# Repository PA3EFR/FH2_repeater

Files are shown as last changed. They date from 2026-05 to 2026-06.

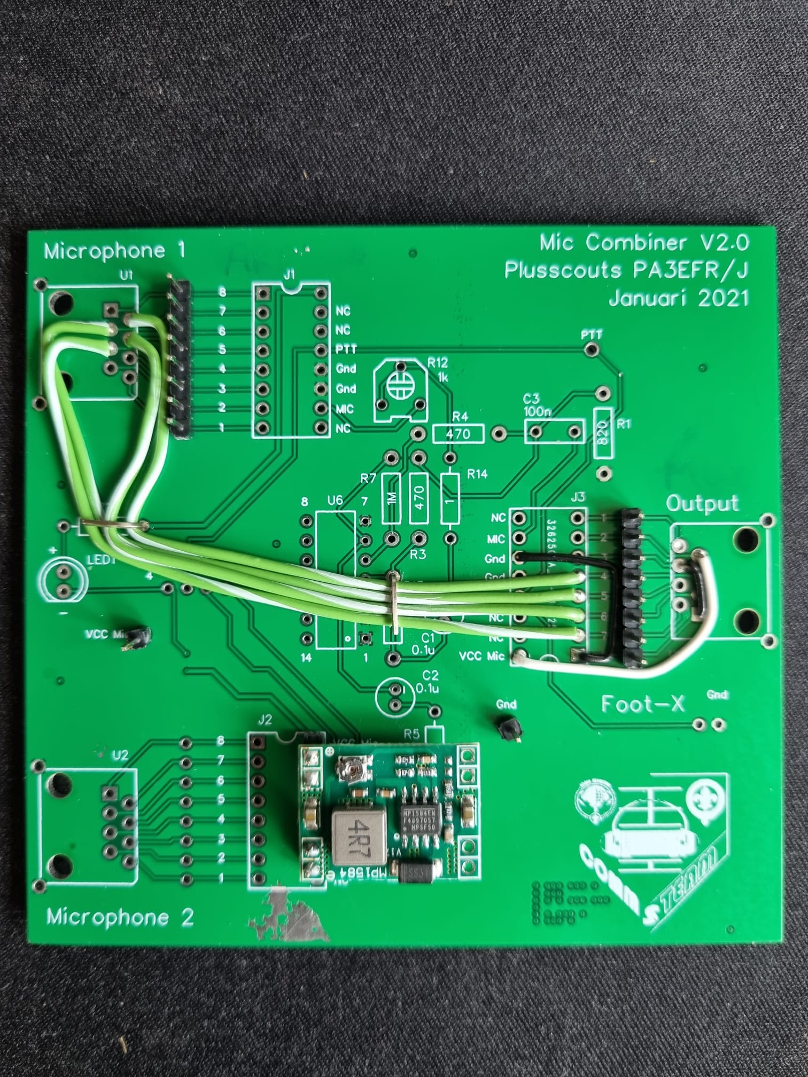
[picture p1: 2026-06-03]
Arduino Nano - 991/WhatsApp Image 2026-06-02 at 10.33.48.jpeg

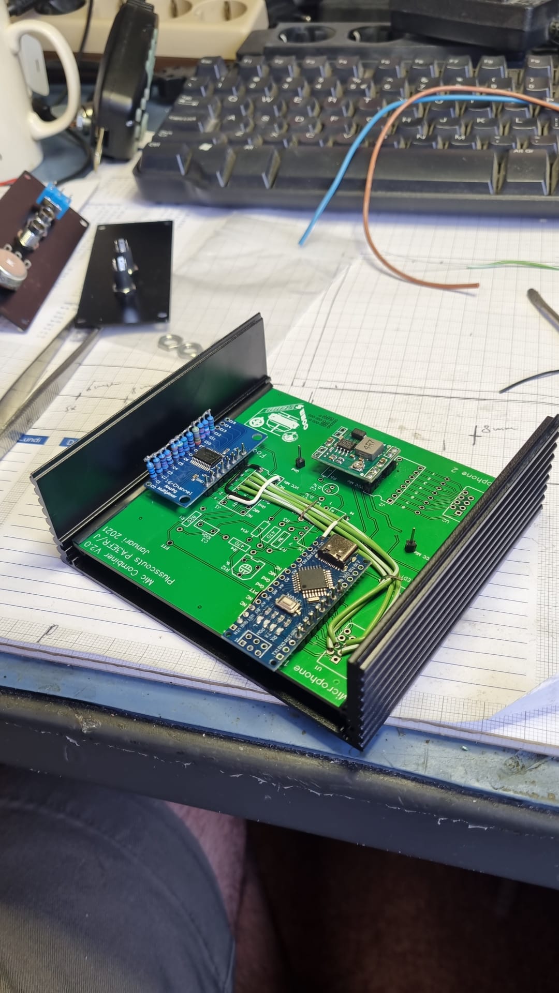
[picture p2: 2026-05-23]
Arduino Nano - 991/WhatsApp Image 2026-05-23 at 11.17.42.jpeg

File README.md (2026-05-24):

**FH-2 Repeater - Functional and Technical Descriptions**

**Functional Description**
The FH-2 Repeater is an Arduino NANO-based system that provides automated control for the Yaesu FH-2 Voice keyer, enabling users to send pre-programmed (CQ) messages at configurable intervals. This controller bridges the gap between traditional manual keying and modern automation, making it particularly useful for contest stations and field operations where consistent, timed CQ transmissions are essential.

The system operates by reading the FH-2's button matrix through an analog voltage sensing mechanism, where each button produces a distinct voltage level through a resistor network. When a button is pressed, the controller activates the corresponding channel on a 16-channel analog multiplexer (74HC4067) to send the appropriate control pulse to the FH-2 unit. The core functionality centers on the interval repeat feature, which allows buttons 1 through 5 to automatically repeat their transmission at user-defined intervals ranging from 10 to 60 seconds. A front-panel potentiometer provides real-time adjustment of the interval timing, while a toggle switch enables or disables the repeat functionality entirely.

The user interface consists of minimal but effective visual indicators: a pulse LED flashes briefly when a transmission occurs, and a status LED illuminates when an interval cycle is actively running. All system information, including button changes, interval modifications, and cycle status, is streamed to the serial monitor at 9600 baud, allowing operators to verify correct operation and troubleshoot any issues. The interval cycle initiates when button 1, 2, 3, 4, or 5 is pressed and continues automatically until the same button is pressed again or the repeat function is disabled via the toggle switch. Pressing any other button immediately terminates an active interval cycle, providing a quick emergency stop mechanism.

The controller's design philosophy prioritizes reliability and simplicity, using only through-hole components for easy construction and maintenance. The debounce algorithm ensures that only genuine button presses are registered, preventing false triggers from mechanical switch bounce. The multiplexer timeout feature ensures that no channel remains selected indefinitely, protecting both the multiplexer and the connected equipment from potential damage due to software or hardware faults.

**Technical Description**
The FH-2 Repeater employs an Arduino NANO (ATmega328P) as its processing core, utilizing the microcontroller's analog-to-digital converter for button matrix scanning and its digital I/O pins for multiplexer control and LED indication. The pin configuration has been carefully chosen to optimize the limited I/O available on the NANO form factor while maintaining logical organization of the various subsystems.

Pin Assignment Summary:

Function	Pin	Description
ADC Input	A0 (Pin 14)	FH-2 button voltage measurement
Interval Control	A1 (Pin 15)	Potentiometer wiper for interval adjustment
MUX S0-S3	D2-D5 (Pins 2-5)	4-bit multiplexer channel selection
MUX Enable	D6 (Pin 6)	Active-low enable for 74HC4067
Repeat Switch	D7 (Pin 7)	Pullup input for repeat on/off toggle
Pulse LED	D9 (Pin 9)	Visual pulse confirmation indicator
Status LED	D10 (Pin 10)	Interval cycle active indicator
The button detection system operates by measuring the voltage present on pin A0, which is connected to the FH-2's button matrix through a voltage divider network. Each button produces a characteristic voltage between 0.38V and 2.53V, with the controller comparing the measured voltage against a lookup table containing all 13 button voltage thresholds. The tolerance window of ±0.15V ensures reliable detection even when minor voltage variations occur due to power supply fluctuations or temperature drift. The best-match algorithm selects the button whose voltage profile most closely matches the measured value, providing robust detection across the entire button matrix.

The multiplexer interface uses four address lines (S0-S3) to select one of sixteen possible channels, with the enable line (active-low) controlling when the multiplexer output is connected to the FH-2 input. When a pulse is triggered, the multiplexer is enabled, the appropriate channel is selected, and after a 250ms dwell time, the multiplexer is disabled and reset to channel 0. A 2-second timeout ensures the multiplexer returns to a safe state if button press detection fails to complete normally.

The interval system implements a simple state machine with three primary states: idle, active-cycling, and stopped. When the user presses buttons 1-5 while repeat is enabled, the system enters the active-cycling state and records the timestamp of the initial pulse. Every subsequent interval period (configurable 10-60 seconds via potentiometer), the same button pulse is automatically resent until the user presses the same button again to stop, presses a different button to override, or disables the repeat switch. The potentiometer is sampled continuously, and any change in the interval setting is immediately reflected in the cycle timing, allowing real-time adjustment without interrupting the current cycle.

Software architecture follows a modular structure with distinct functions for button detection, multiplexer control, pulse generation, and serial reporting. The main loop implements a cooperative multitasking approach, checking all inputs and updating outputs in sequence at approximately 100Hz. The debounce logic requires two consecutive identical button readings separated by 50ms before accepting a button press as valid, effectively filtering out mechanical bounce artifacts. Serial output uses formatted strings with timestamp information (seconds since startup) to facilitate post-operation analysis and debugging.

The circuit requires a regulated 5V supply capable of delivering approximately 100mA for the Arduino, multiplexer, and LED indicators. Power can be sourced from the USB connection during development or from an external 5V regulator for permanent installation. The FH-2 connection uses a standard 3.5mm stereo jack, with the multiplexer output directly driving the FH-2's button matrix inputs according to the channel mapping defined in the source code.

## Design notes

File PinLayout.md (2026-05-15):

## **Nano Pin Layout**

NANO PINOUT - FH-2 CQ-MACHINE

========================

Voeding:

&#x20; VCC  → 5V (van USB of externe voeding)

&#x20; GND  → GND (massa)

Communicatie:

&#x20; (USB) → Serieel (9600 baud)

Analoge pinnen:

&#x20; A0   → FH-2 ADC input (weerstandsladder)

&#x20; A1   → Potmeter interval (10kΩ naar 5V en GND)

Digitale pinnen:

&#x20; D5   → MUX S0 (address bit 0)

&#x20; D4   → MUX S1 (address bit 1)

&#x20; D3   → MUX S2 (address bit 2)

&#x20; D2   → MUX S3 (address bit 3)

&#x20; D6   → MUX \~EN (enable, actief laag)

&#x20; D7   → Repeat schakelaar (naar GND = uit)

&#x20; D9   → Puls LED (ROOD, via 220Ω naar GND)

&#x20; D10  → Status LED (GROEN, via 220Ω naar GND)

## 

## **Aansluitschema Nano**

Arduino Nano          74HC4067 MUX

\---------            -------------

&#x20; D5 (S0)    ────    S0

&#x20; D4 (S1)    ────    S1

&#x20; D3 (S2)    ────    S2

&#x20; D2 (S3)    ────    S3

&#x20; D6 (\~EN)   ────    \~EN

&#x20; D7         ────    Repeat schakelaar (naar GND)

&#x20; D9         ────    \[RODE LED] ── 220Ω ── GND

&#x20; D10        ────    \[GROENE LED] ── 220Ω ── GND

&#x20; A0         ────    FH-2 ADC signaal

&#x20; A1         ────    Potmeter signaal

&#x20; 5V         ────    VCC (MUX en potmeter)

&#x20; GND        ────    GND (alles)

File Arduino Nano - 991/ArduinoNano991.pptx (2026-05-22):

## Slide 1

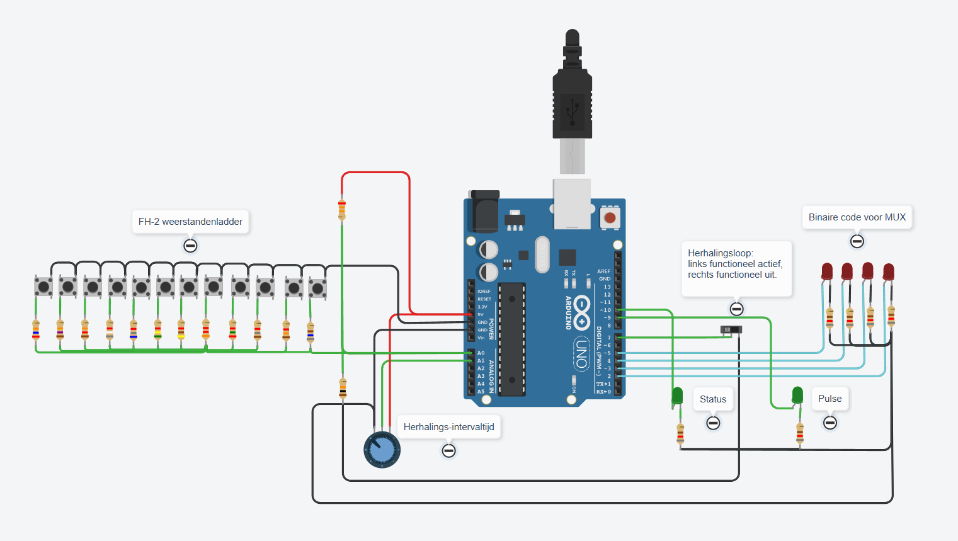
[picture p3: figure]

Arduino NANO 991

Resistor ladder

MUX code

Repeat Switch:
Left: active

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
Interval timer

Status

Pulse

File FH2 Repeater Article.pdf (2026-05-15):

### Automating the Yaesu FH-2 with an Arduino NANO

As Radio Scouts we are involved and organize several HF radio activities. Depending on conditions and the length of the event it could very handy to use a voice keyer. Our inventory consists mainly of Yaesu equipment so the voice keyer choice is limited to a FH-2 remote device. Unfortunately, repetition of the recall of a memory slot depends on the sole finger action of the operators in charge, sometimes supported by a scout who sits aside the operator. It was during poor conditions, hence repetative finger operations on the FH-2, that the
idea was born to make a FH-2 Repeater which repeats memory slot recalls with
predefined (but adjustable) interval times.

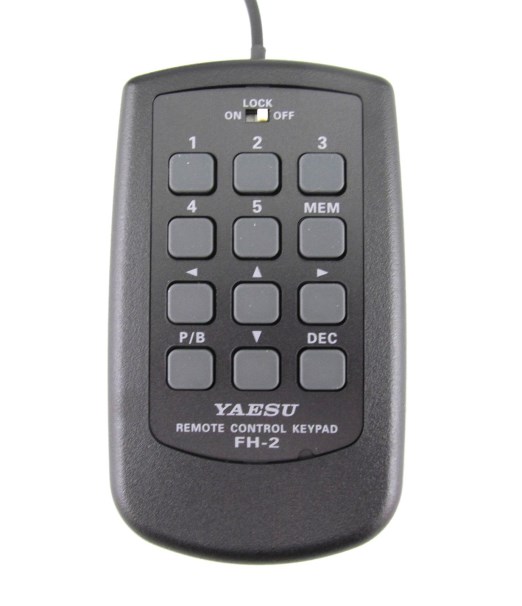
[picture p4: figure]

The FH-2 Repeater described in this article is a small, Arduino-based controller that plugs into the Yaesu FH-2 Morse keyer connector of your Yaesu transceiver and sends your pre-programmed messages automatically, at whatever interval you choose. It is not a commercial product. It is a homebrew project, designed from scratch using only through-hole components, and it invites you to build it yourself, improve upon it, and make it your own.

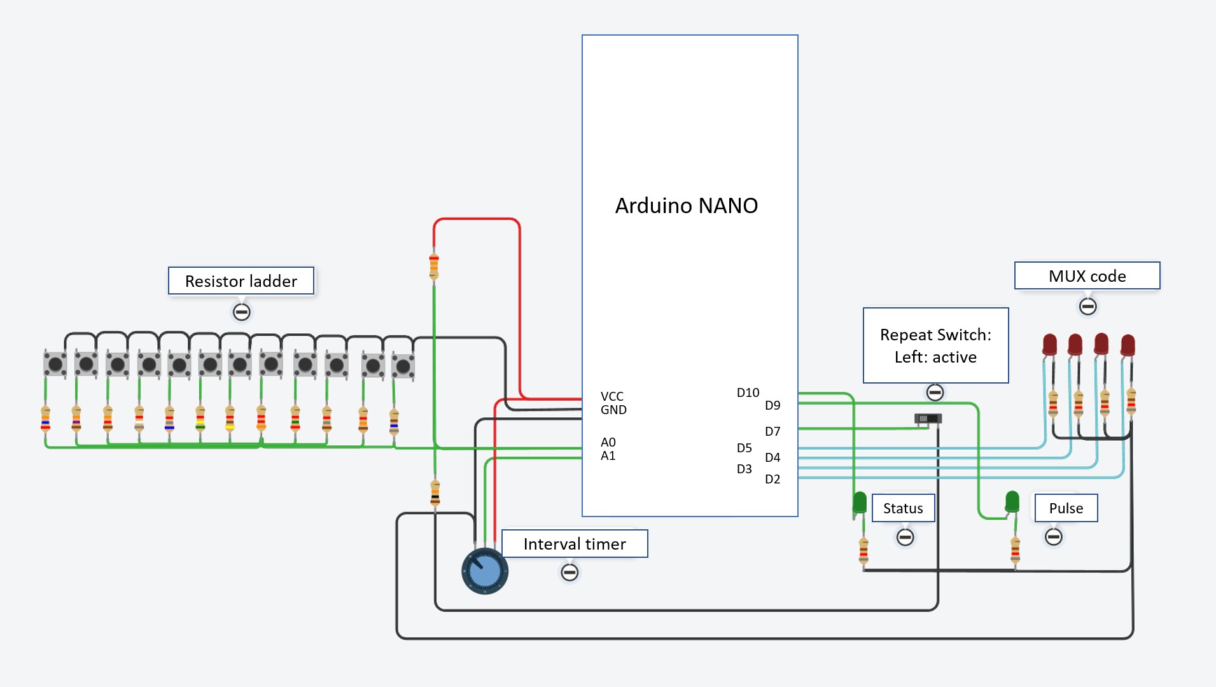
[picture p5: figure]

What Does It Do?

The FH-2 Repeater takes over the repetitive task of triggering the FH-2’s memory keyer buttons at regular intervals. In practical terms, you press a button on the FH-2 (or on the controller), and from that moment onward the controller automatically resends that same message every 10 to 60 seconds — the exact interval is set by turning a front-panel potentiometer. You carry on with logging, antenna switching, or enjoy a well-deserved cup of coffee.

A front-panel toggle switch turns the repeat function on and off entirely. Two LEDs give you at-a-glance confirmation: one flashes each time a transmission is triggered, and the other glows steadily to tell you that an automatic cycle is running. If you need to stop immediately — a rare opening on another band, an urgent call on the radio — pressing any button other than the active one cancels the cycle instantly.

Testing the design, ideas and software the TinkerCad online simulator is an ideal tool. Together with a helpfull AI machine the design was fine-tuned and developed before it was taken to the breadboard components.

All activity is also reported in real time over the serial port at 9600 baud, complete with timestamps, so you can connect a laptop, open the serial monitor, and have a detailed log of every event during your operating session.

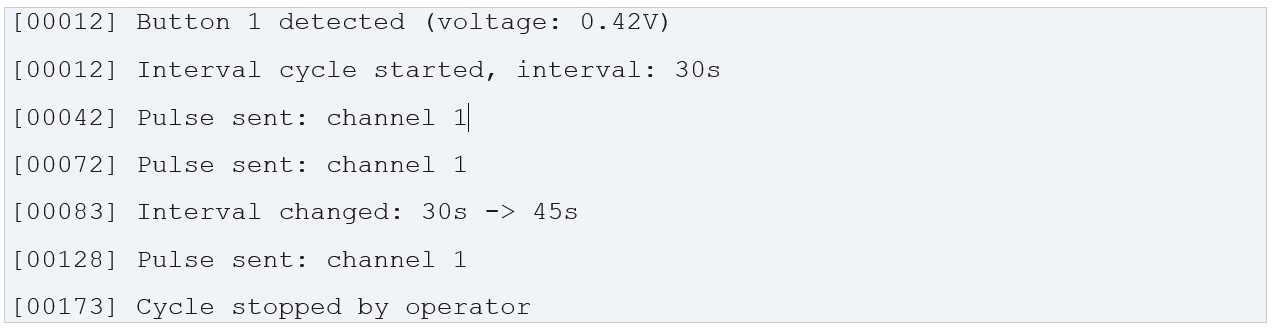
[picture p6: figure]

How Does It Work?

Reading the FH-2 Button Matrix

The FH-2 exposes its button matrix through a resistor network, and each button produces a distinct voltage on the output line. The controller measures this voltage with the Arduino’s built-in analogue-to-digital converter on pin A0. Each of the FH-2 buttons produces a characteristic voltage between about 0.38 V and 2.53 V, and the software compares each reading against a lookup table, accepting a match if it falls within a ±0.15 V tolerance window. A best-match algorithm handles the edge cases, making detection robust against minor power supply variations or temperature drift.

The Multiplexer — The Key to Pressing Buttons Electronically

To send a button press to the FH-2, the controller needs to briefly close the same electrical contact that a physical button would close. This is done through a 74HC4067 sixteen-channel analogue multiplexer — a cheap, widely available CMOS chip that costs only a few cents. Four address lines from the Arduino select which of the sixteen channels is connected, and an active-low enable line controls when the output is active.

When a transmission is due, the Arduino selects the correct channel, enables the multiplexer for 250 milliseconds, then disables it and resets to channel zero. A 2-second timeout in the software ensures the multiplexer always returns to a safe state, even if something unexpected interrupts the sequence.

The Interval State Machine

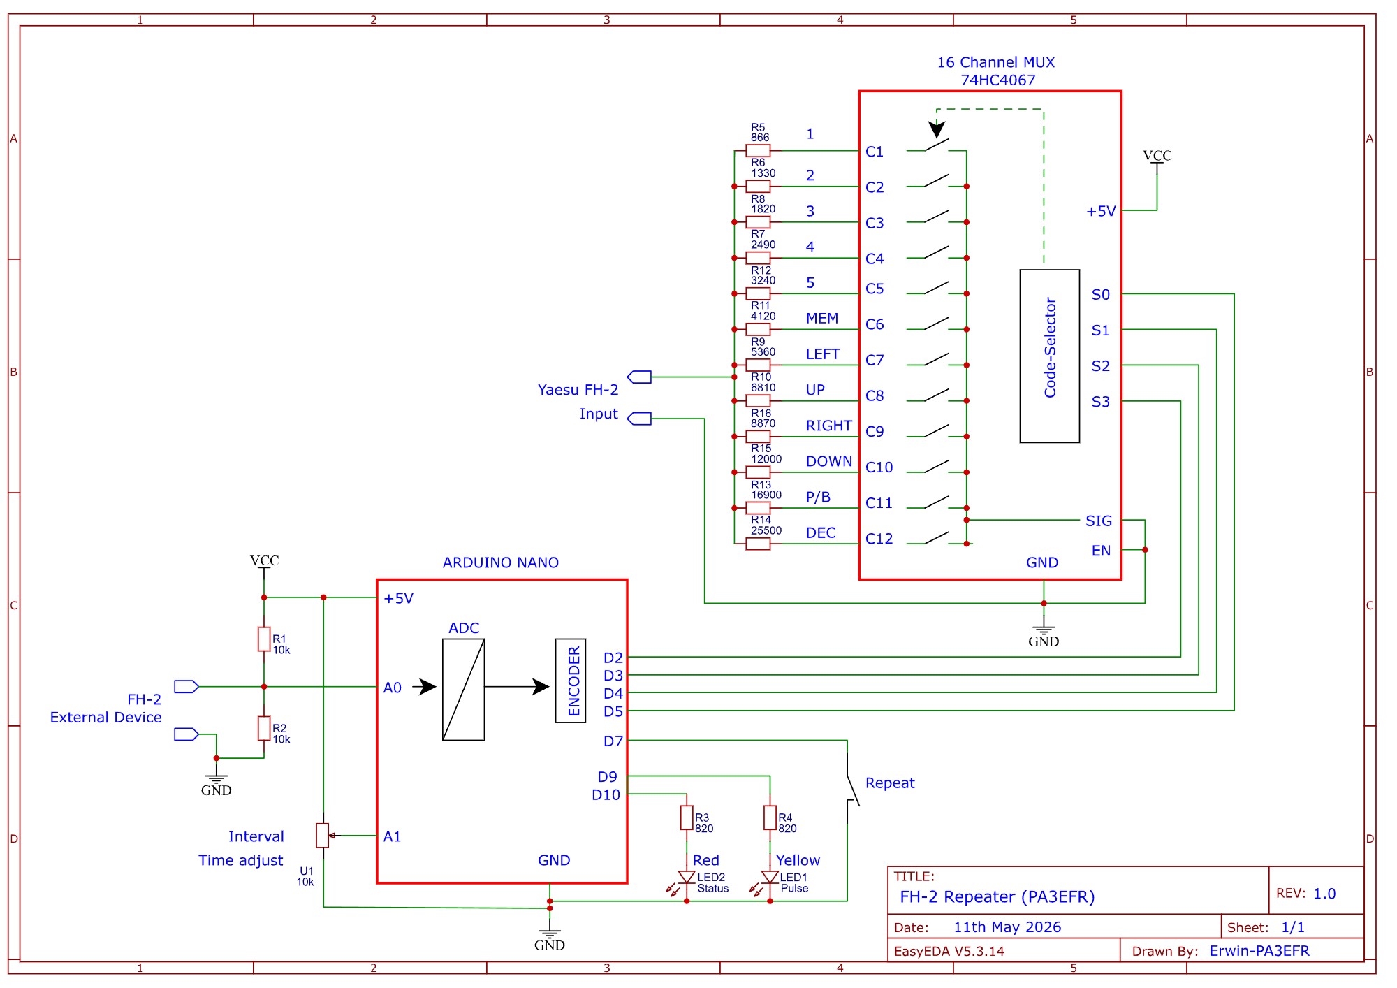
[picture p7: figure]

The heart of the software is a simple three-state machine: idle, active-cycling, and stopped. Pressing buttons 1 through 5 while the repeat switch is on moves the system into the active-cycling state. From that point, the software checks the elapsed time against the potentiometer reading on every pass through the main loop — running at approximately 100 Hz — and triggers a new pulse when the interval expires. Turning the potentiometer takes effect immediately, without interrupting the current cycle, which is very useful for real-time adjustments during a contest.

Debounce and Reliability

Mechanical switches bounce — they make and break contact several times in the first millisecond after being pressed. The controller deals with this by requiring two identical consecutive readings separated by 50 milliseconds before accepting a button press as genuine. This simple debounce algorithm is robust in practice and adds no perceptible delay for the operator.

Circuit and Components

The circuit is deliberately simple. There are no surface-mount components, no exotic parts, and nothing that cannot be sourced from any of the usual suppliers. The complete bill of materials is short:
- Arduino NANO (ATmega328P) — the processing core
- 74HC4067 16-channel analogue multiplexer — the button emulator
- 10 kΩ linear potentiometer — interval adjustment
- SPDT toggle switch — repeat on/off
- Two LEDs with appropriate series resistors (pulse and status)
- 3.5 mm stereo jack socket — FH-2 connection
- Assorted resistors and decoupling capacitors
- Stripboard or a custom PCB
The Arduino is powered from USB during development and can be powered from an external 5 V regulator in a permanent installation. Total current consumption is modest — around 100 mA at most.

The Software

The firmware is written in standard Arduino C++ and follows a straightforward modular structure. There are separate functions for button detection, multiplexer control, pulse generation, and serial reporting. The main loop uses a cooperative multitasking approach, cycling through all inputs and outputs at roughly 100 Hz. This keeps the code easy to read, easy to modify, and easy to extend.

Build It Yourself — You Can Do This

This project is accessible to any amateur who has soldered a few components and loaded a sketch onto an Arduino. If you have never done either of those things, this is an excellent first project: the circuit is forgiving, the components are inexpensive, and the Arduino ecosystem has outstanding documentation and a large, helpful community.

The through-hole construction is intentional. Every component can be held in place with two fingers while you solder it. Every joint can be inspected and reflowed if needed. There are no heat-sensitive plastic packages to worry about, no tiny pads to bridge accidentally, and no need for a microscope or hot-air rework station.

Function | Pin | Description
ADC Input | A0 (Pin 14) | FH-2 button voltage measurement
Interval Control | A1 (Pin 15) | Potentiometer wiper for interval adjustment
MUX S0–S3 | D2–D5 (Pins 2–5) | 4-bit multiplexer channel selection
MUX Enable | D6 (Pin 6) | Active-low enable for 74HC4067
Repeat Switch | D7 (Pin 7) | Pull-up input for repeat on/off toggle
Pulse LED | D9 (Pin 9) | Visual pulse confirmation indicator
Status LED | D10 (Pin 10) | Interval cycle active indicator

A Note for Those Who No Longer Solder

Not every amateur is in a position to build a project like this. Perhaps your eyesight makes fine soldering difficult, or your hands are no longer steady, or you simply do not have a workshop any more. That is entirely understood, and it is not a failure.

The intention of publishing this design openly is not to exclude, but to share. If the project interests you, perhaps a club member or a younger amateur in your circle would be willing to build it for you — a joint effort that passes on skills as well as producing a useful piece of equipment. The design is simple enough that it makes an excellent mentoring project.

For Jamboree On The Air this could well be a good solder project in the summer months for the scouts to take on and use during the JOTA in October. You will not regret the effort.

Alternatively, the software and circuit description here may be enough to inspire someone you know to adapt

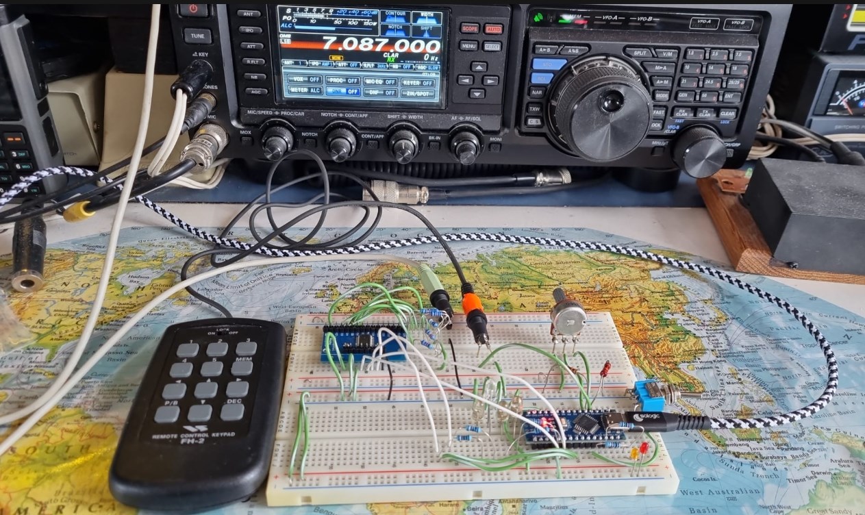
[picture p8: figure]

the principle to a different controller or a different keyer altogether. Good ideas have a way of multiplying.

Conclusion

The FH-2 Repeater is a practical solution to a real problem, built from components that cost less than a contest entry fee and assembled in an evening. It is not the last word in automation, and it was never intended to be. It is a starting point: a working, documented design that you can build, understand, modify, and improve.

On behalf of the Radio Scouting Fellowship of PA3EFR/J, 73 and good luck with the build.

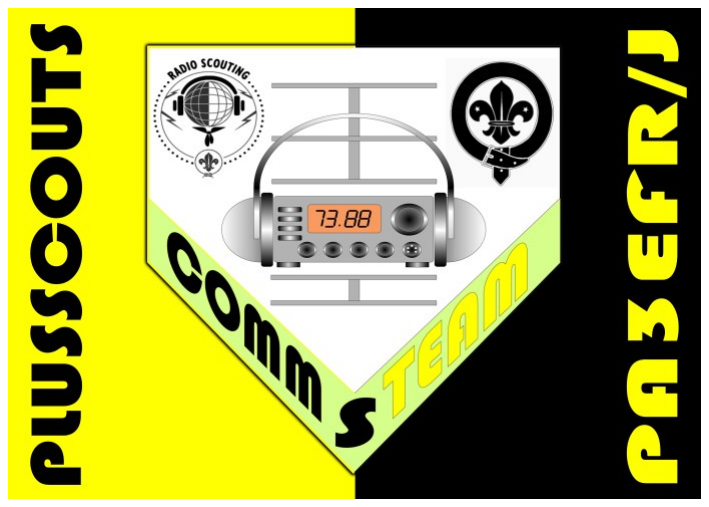
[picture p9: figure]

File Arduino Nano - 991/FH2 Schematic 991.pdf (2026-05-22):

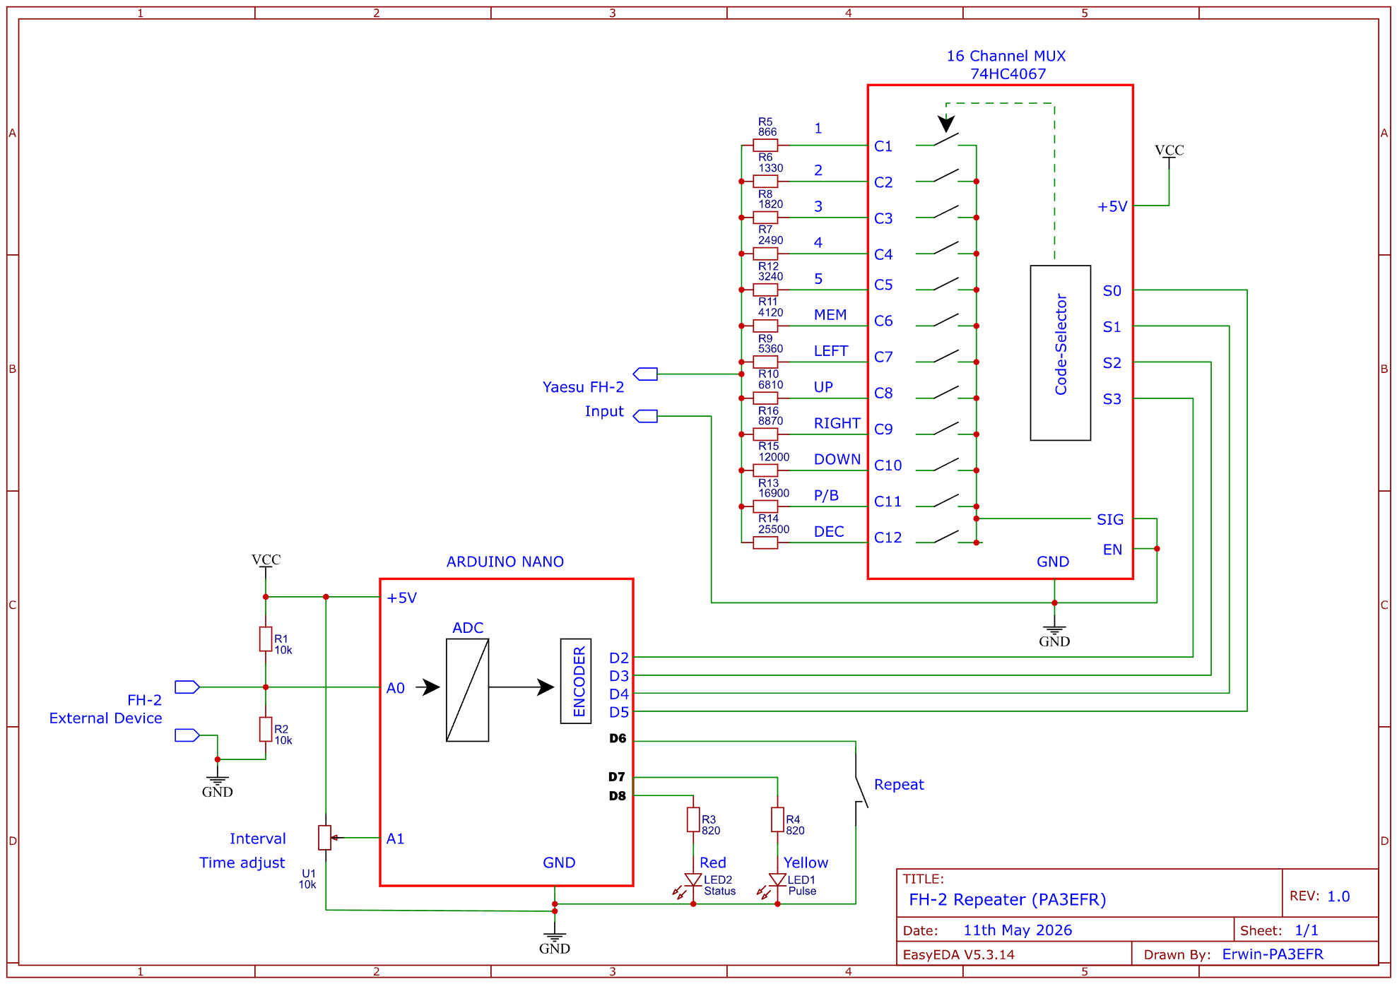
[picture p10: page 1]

D7
D8

D6

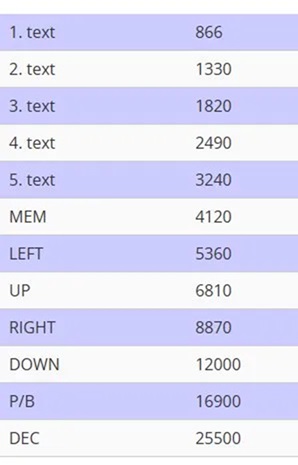
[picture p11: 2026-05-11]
ResistorMatrix.jpg

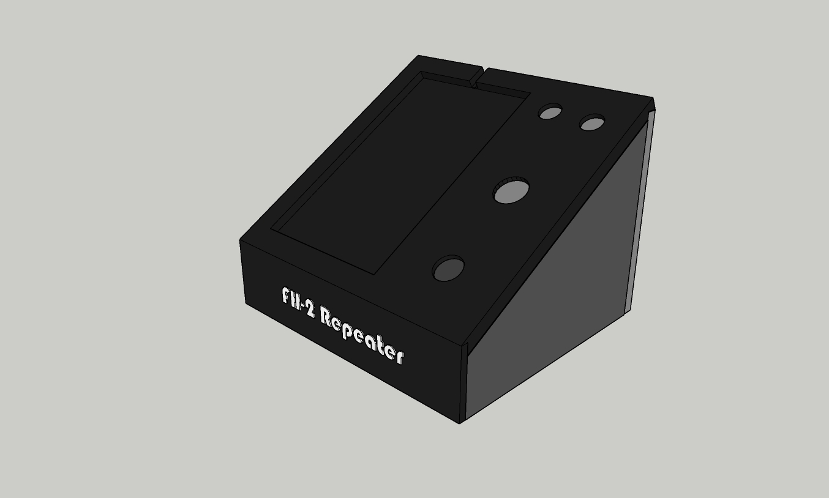
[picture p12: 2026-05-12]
FH2_Repeater.jpg

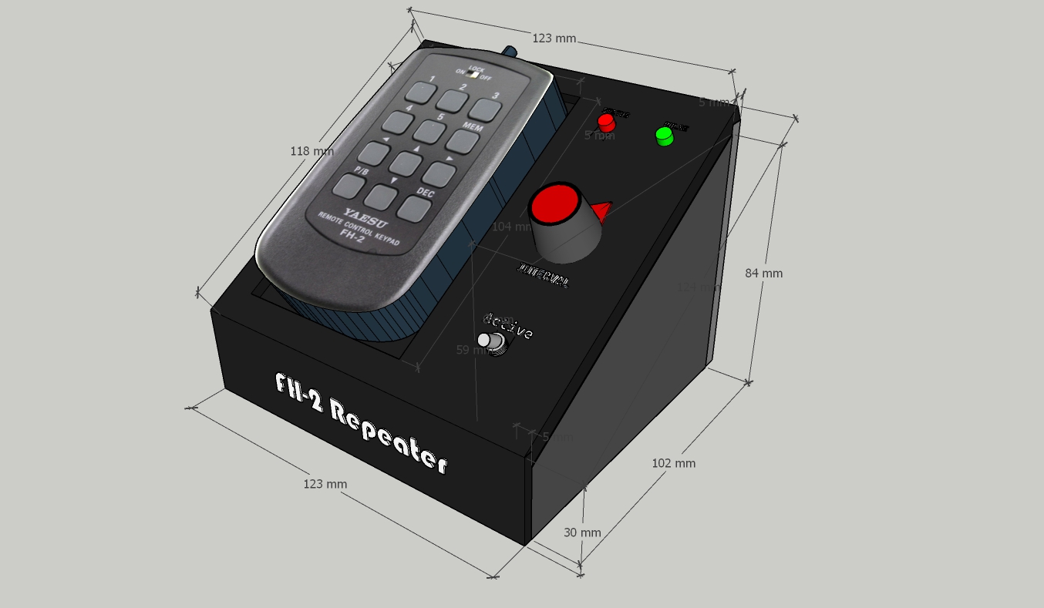
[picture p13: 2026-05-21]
FH2_repeater_complete.jpg

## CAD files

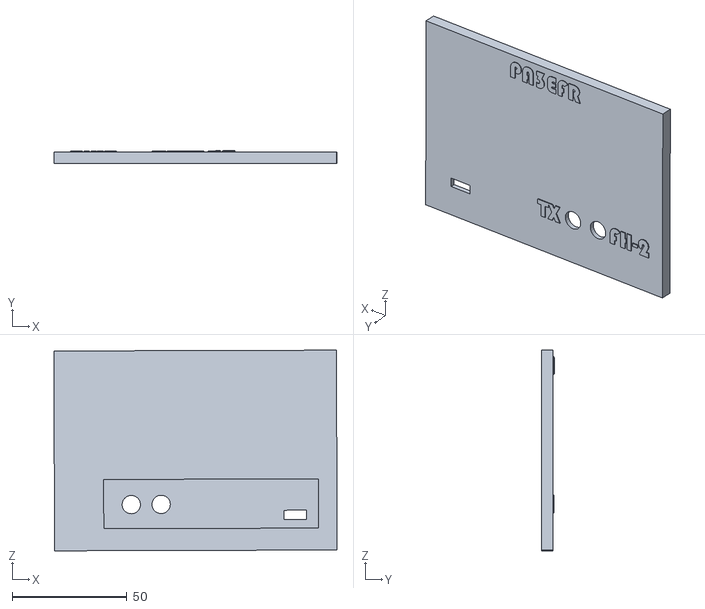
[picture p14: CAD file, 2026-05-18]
STLs/Achterkant_FH2_repeater.stl
123.2 x 5.49 x 87.4

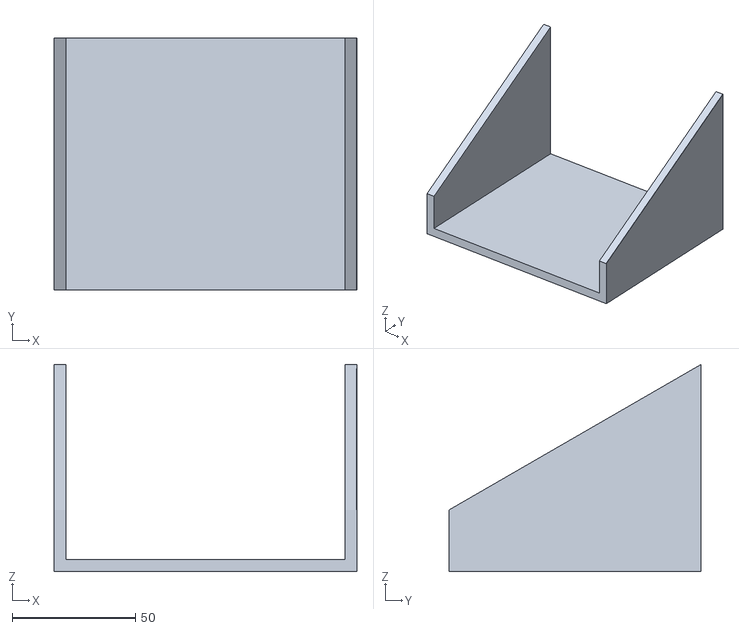
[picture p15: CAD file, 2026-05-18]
STLs/Zijkant_FH2_repeater.stl
123.0 x 102.4 x 84.1

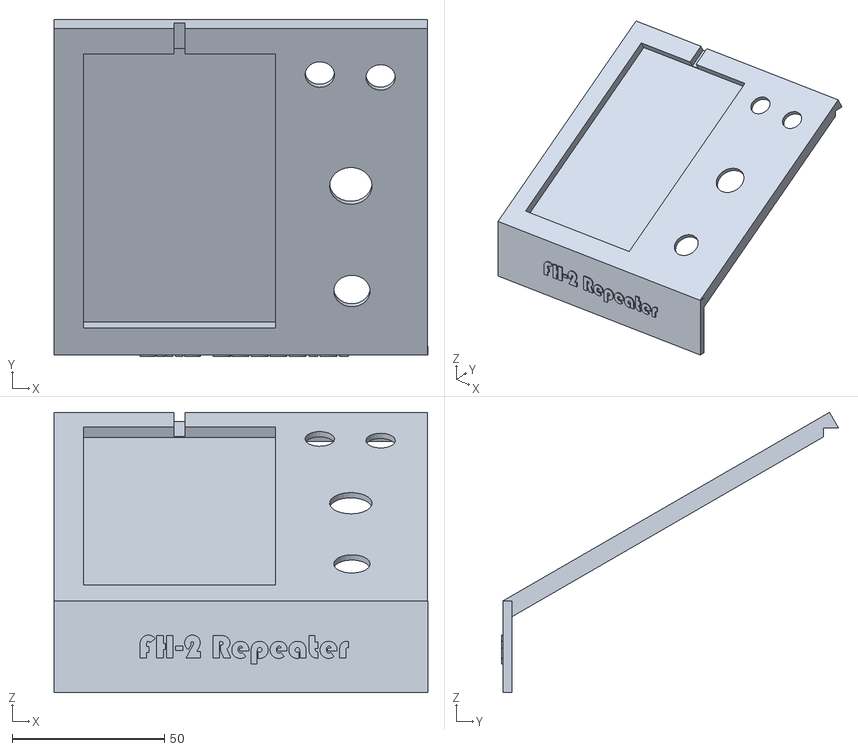
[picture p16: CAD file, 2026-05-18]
STLs/Frontje_FH2_repeater.stl
123.0 x 110.9 x 92.2

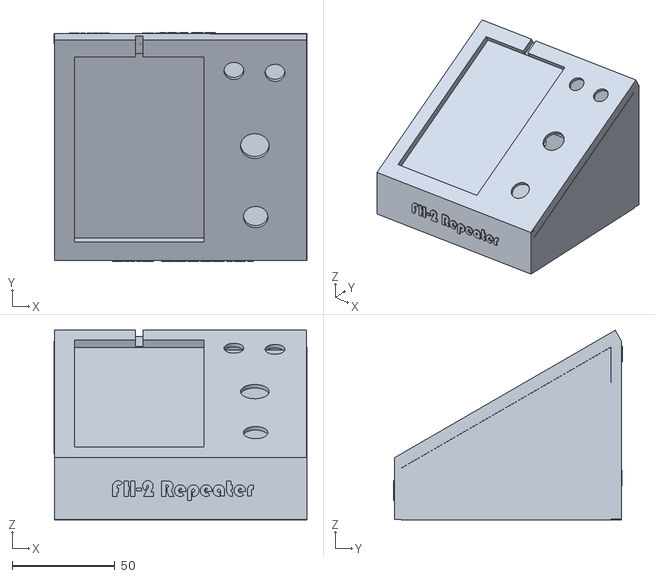
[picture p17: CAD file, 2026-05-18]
STLs/FH2_repeater.stl
123.2 x 111.4 x 92.3

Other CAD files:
Frontje_FH2_repeater.skp

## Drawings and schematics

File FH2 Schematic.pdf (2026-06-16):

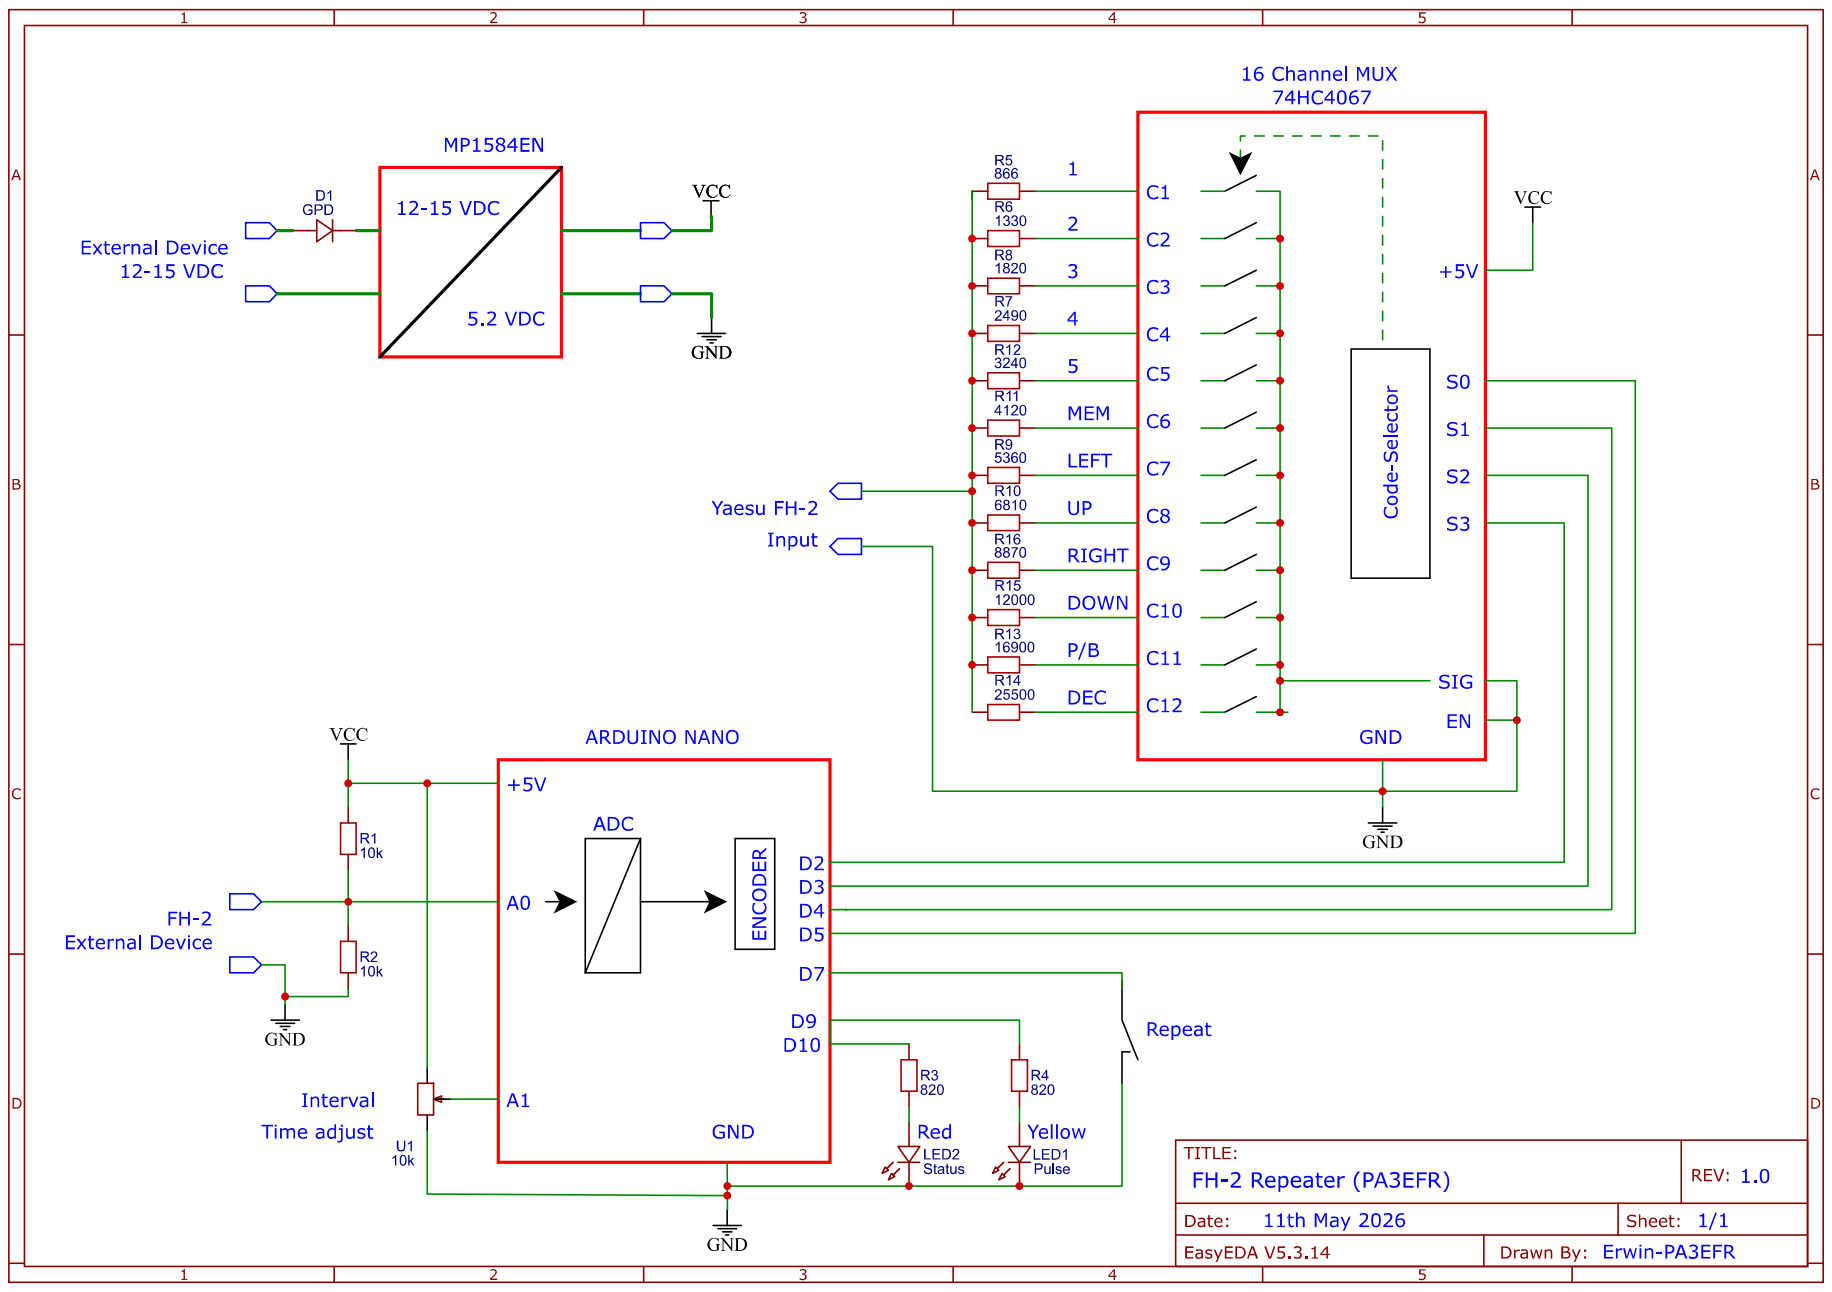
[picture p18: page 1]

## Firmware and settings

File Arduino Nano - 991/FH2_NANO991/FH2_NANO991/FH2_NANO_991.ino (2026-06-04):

// ============================================================
// FH-2 CQ-machine controller — Arduino NANO versie 6
// Met intervaltijd weergave in monitor
// Repeat met interval beperkt tot knoppen 1, 2, 3, 4, 5
// ============================================================

// ---------------------------------------------------------------------------
// PULS DEFINITIES
// ---------------------------------------------------------------------------
#define PULS_FH2     "FH-2"
#define PULS_AUTO    "AUTO"

// ---------------------------------------------------------------------------
// STATUS DEFINITIES
// ---------------------------------------------------------------------------
#define STATUS_GESTOPT "GESTOPT"
#define STATUS_ACTIEF  "ACTIEF"

// ---------------------------------------------------------------------------
// PIN DEFINITIES - Nano specifiek
// ---------------------------------------------------------------------------
#define PIN_S3           5   // Nano D2: MUX S0
#define PIN_S2           4   // Nano D3: MUX S1
#define PIN_S1           3   // Nano D4: MUX S2
#define PIN_S0           2   // Nano D5: MUX S3
#define PIN_REPEAT_EN    6   // Nano D7: Repeat enable (LOW=uit, HIGH=aan)
#define PIN_PULSE_LED    7   // Nano D9: Puls indicator LED
#define PIN_STATUS_LED   8  // Nano D10: Status LED (GROEN)
#define PIN_POTMETER     A1  // Nano A1: Potmeter interval
#define PIN_ADC_IN       A0  // Nano A0: ADC ingang FH-2

// ---------------------------------------------------------------------------
// CONSTANTEN
// ---------------------------------------------------------------------------
#define ADC_MAX         1023
#define VREF            5.0
#define POT_MAX         1023
#define MIN_INTERVAL    10       // minimale interval in seconden
#define MAX_INTERVAL    60      // maximale interval in seconden
#define MUX_TIMEOUT_MS  2000    // 2 seconden timeout
#define PULSE_DURATION  250     // 500ms pulsduur
#define DEBOUNCE_MS     50      // 50ms debounce
#define TOLERANTIE      0.15    // Spannings tolerantie voor knopdetectie

// ---------------------------------------------------------------------------
// GEMETEN SPANNINGEN EN KNOPEN
// ---------------------------------------------------------------------------
#define NUM_BUTTONS 13

const float BUTTON_VOLTAGES[NUM_BUTTONS] = {
    2.53,   // 0: Geen knop (rust) - hoogste spanning
    0.38,   // 1: 1.text - laagste spanning
    0.51,   // 2: 2.text
    0.667,  // 3: 3.text
    0.817,  // 4: 4.text
    1.001,  // 5: 5.text
    1.165,  // 6: MEM
    1.274,  // 7: Links (LEFT)
    1.453,  // 8: Up (UP)
    1.628,  // 9: Rechts (RIGHT)
    1.782,  // 10: Down (DOWN)
    1.922,  // 11: P/B
    2.09    // 12: DEC
};

const char* BUTTON_NAMES[NUM_BUTTONS] = {
    "-",       // 0: Geen knop
    "1",       // 1: 1.text
    "2",       // 2: 2.text
    "3",       // 3: 3.text
    "4",       // 4: 4.text
    "5",       // 5: 5.text
    "MEM",     // 6: MEM
    "Links",   // 7: LEFT
    "Up",      // 8: UP
    "Rechts",  // 9: RIGHT
    "Down",    // 10: DOWN
    "P/B",     // 11: P/B
    "DEC"      // 12: DEC
};

const int MUX_CHANNELS[NUM_BUTTONS] = {
    0, 1, 2, 3, 4, 5, 6, 7, 8, 9, 10, 11, 12
};

// ---------------------------------------------------------------------------
// VARIABELEN
// ---------------------------------------------------------------------------
int previousButton = -1;
int activeButton = -1;
unsigned long lastButtonPress = 0;
bool intervalActive = false;
unsigned long lastIntervalPulse = 0;
int intervalSeconds = 5;
bool repeatEnabled = true;
unsigned long lastPulseTime = 0;
bool pulseLedState = false;
int lastPotValue = -1;

// Vorige waarden voor change detection
int prev_intervalSeconds = -1;
bool prev_intervalActive = false;
bool prev_repeatEnabled = false;
int prev_detectedButton = -1;

// ---------------------------------------------------------------------------
// SETUP
// ---------------------------------------------------------------------------
void setup() {
    Serial.begin(9600);
    while (!Serial) {
        delay(100);
    }

    // Configureer pinnen
    pinMode(PIN_S0, OUTPUT);
    pinMode(PIN_S1, OUTPUT);
    pinMode(PIN_S2, OUTPUT);
    pinMode(PIN_S3, OUTPUT);
    pinMode(PIN_REPEAT_EN, INPUT_PULLUP);
    pinMode(PIN_PULSE_LED, OUTPUT);
    pinMode(PIN_STATUS_LED, OUTPUT);

    // MUX uit bij opstart
     setMuxChannel(0);

    // LED's uit
    digitalWrite(PIN_PULSE_LED, LOW);
    digitalWrite(PIN_STATUS_LED, LOW);

    // Lees initiële interval
    intervalSeconds = readInterval();
    lastPotValue = intervalSeconds;
    prev_intervalSeconds = intervalSeconds;

    // Toon info
    printHeader();
    printCurrentSettings();

    Serial.println(F("=========================================="));
    Serial.println(F("  Systeem gereed. Wacht op FH-2 knop..."));
    Serial.println(F("==========================================\n"));

    delay(500);
}

// ---------------------------------------------------------------------------
// KNOP DETECTIE
// ---------------------------------------------------------------------------
bool canRepeatWithInterval(int buttonIndex) {
    // Alleen knoppen 1, 2, 3, 4, 5 kunnen de interval-cyclus gebruiken
    return (buttonIndex >= 1 && buttonIndex <= 5);
}

int detectButtonByVoltage(int adcValue) {
    float measuredVoltage = (adcValue * VREF) / ADC_MAX;

    int bestMatch = 0;
    float minDiff = 999.0;

    for (int i = 0; i < NUM_BUTTONS; i++) {
        float diff = abs(BUTTON_VOLTAGES[i] - measuredVoltage);
        if (diff < minDiff) {
            minDiff = diff;
            bestMatch = i;
        }
    }

    if (minDiff < TOLERANTIE) {
        return bestMatch;
    }

    return 0;
}

// ---------------------------------------------------------------------------
// HEADER WEERGAVE
// ---------------------------------------------------------------------------
void printHeader() {
    Serial.println(F("=========================================="));
    Serial.println(F("  FH-2 CQ-machine - Arduino NANO v6"));
    Serial.println(F("  Met intervaltijd weergave"));
    Serial.println(F("=========================================="));
    Serial.println();
    Serial.println(F("NANO PIN LAYOUT:"));
    Serial.println(F("------------------------------------------"));
    Serial.println(F("  A0 = ADC FH-2 input"));
    Serial.println(F("  A1 = Potmeter interval"));
    Serial.println(F("  D5-D2 = MUX address (S0-S3)"));
    Serial.println(F("  D6 = Repeat schakelaar (GND=uit)"));
    Serial.println(F("  D7 = Puls LED"));
    Serial.println(F("  D8 = Status LED (GROEN)"));
    Serial.println();
}

// ---------------------------------------------------------------------------
// HUIDIGE INSTELLINGEN WEERGAVE
// ---------------------------------------------------------------------------
void printCurrentSettings() {
    Serial.println(F("HUIDIGE INSTELLINGEN:"));
    Serial.println(F("------------------------------------------"));
    Serial.print(F("  Interval: "));
    Serial.print(intervalSeconds);
    Serial.println(F(" sec"));
    Serial.print(F("  Repeat: "));
    Serial.println(repeatEnabled ? F("AAN") : F("UIT"));
    Serial.println();
}

// ---------------------------------------------------------------------------
// MUX KANAAL INSTELLEN
// ---------------------------------------------------------------------------
void setMuxChannel(int channel) {
    digitalWrite(PIN_S0, (channel & 1) ? HIGH : LOW);
    digitalWrite(PIN_S1, (channel & 2) ? HIGH : LOW);
    digitalWrite(PIN_S2, (channel & 4) ? HIGH : LOW);
    digitalWrite(PIN_S3, (channel & 8) ? HIGH : LOW);
}

// ---------------------------------------------------------------------------
// PULS VERZENDEN
// ---------------------------------------------------------------------------
void sendPulse(int muxChannel, const char* pulseType) {
    setMuxChannel(muxChannel);

    delay(PULSE_DURATION);

    setMuxChannel(0);

    // Pulse LED activeren
    digitalWrite(PIN_PULSE_LED, HIGH);
    lastPulseTime = millis();
    pulseLedState = true;

    Serial.println();
    Serial.print(F("["));
    Serial.print(millis() / 1000);
    Serial.print(F("s] PULS: "));
    Serial.print(BUTTON_NAMES[activeButton]);
    Serial.print(F(" | Type: "));
    Serial.print(pulseType);
    Serial.print(F(" | Interval: "));
    Serial.print(intervalSeconds);
    Serial.print(F("s | MUX: "));
    Serial.println(muxChannel);
}

// ---------------------------------------------------------------------------
// INTERVAL LEZEN
// ---------------------------------------------------------------------------
int readInterval() {
    int potValue = analogRead(PIN_POTMETER);
    int interval = map(potValue, 0, POT_MAX, MIN_INTERVAL, MAX_INTERVAL);
    return interval;
}

// ---------------------------------------------------------------------------
// STATUS WIJZIGING REPORTEN
// ---------------------------------------------------------------------------
void reportStatusChange(const char* what, const char* oldValue, const char* newValue) {
    Serial.print(F("["));
    Serial.print(millis() / 1000);
    Serial.print(F("s] STATUS: "));
    Serial.print(what);
    Serial.print(F(" veranderd: "));
    Serial.print(oldValue);
    Serial.print(F(" -> "));
    Serial.println(newValue);
}

// ---------------------------------------------------------------------------
// KNOP WIJZIGING REPORTEN
// ---------------------------------------------------------------------------
void reportButtonChange(int oldButton, int newButton, int adcValue) {
    Serial.println();
    Serial.print(F("["));
    Serial.print(millis() / 1000);
    Serial.print(F("s] KNOP: "));
    Serial.print(BUTTON_NAMES[oldButton]);
    Serial.print(F(" -> "));
    Serial.print(BUTTON_NAMES[newButton]);
    Serial.print(F(" (ADC="));
    Serial.print(adcValue);
    Serial.print(F(", "));
    Serial.print((adcValue * VREF) / ADC_MAX, 2);
    Serial.print(F("V) | Interval: "));
    Serial.print(intervalSeconds);
    Serial.println(F("s"));
}

// ---------------------------------------------------------------------------
// INTERVAL CYCLUS START REPORTEN
// ---------------------------------------------------------------------------
void reportCycleStart() {
    Serial.println();
    Serial.println(F("=========================================="));
    Serial.println(F(">>> INTERVAL CYCLUS GESTART"));
    Serial.print(F(">>> Knop: "));
    Serial.print(BUTTON_NAMES[activeButton]);
    Serial.print(F(" | Interval: "));
    Serial.print(intervalSeconds);
    Serial.println(F(" sec"));
    Serial.print(F(">>> Repeat: "));
    Serial.println(repeatEnabled ? F("AAN") : F("UIT"));
    Serial.println(F(">>> Druk opnieuw op dezelfde knop om te stoppen"));
    Serial.println(F("=========================================="));
    Serial.println();
}

// ---------------------------------------------------------------------------
// INTERVAL CYCLUS STOP REPORTEN
// ---------------------------------------------------------------------------
void reportCycleStop() {
    Serial.println();
    Serial.println(F("=========================================="));
    Serial.println(F(">>> INTERVAL CYCLUS GESTOPT"));
    Serial.println(F("=========================================="));
    Serial.println();
}

// ---------------------------------------------------------------------------
// INTERVAL WIJZIGING REPORTEN
// ---------------------------------------------------------------------------
void reportIntervalChange(int oldInterval, int newInterval) {
    Serial.print(F("["));
    Serial.print(millis() / 1000);
    Serial.print(F("s] INFO: Interval gewijzigd: "));
    Serial.print(oldInterval);
    Serial.print(F("s -> "));
    Serial.print(newInterval);
    Serial.println(F("s"));
}

// ---------------------------------------------------------------------------
// HOOFDLUS
// ---------------------------------------------------------------------------
void loop() {
    unsigned long now = millis();
    int adcValue = analogRead(PIN_ADC_IN);
    int detectedButton = detectButtonByVoltage(adcValue);
    repeatEnabled = (digitalRead(PIN_REPEAT_EN) == HIGH);

    // Pulse LED timer
    if (pulseLedState && (now - lastPulseTime >= 1000)) {
        digitalWrite(PIN_PULSE_LED, LOW);
        pulseLedState = false;
    }

    // Interval bijwerken
    int currentInterval = readInterval();
    if (currentInterval != lastPotValue) {
        lastPotValue = currentInterval;
        intervalSeconds = currentInterval;
    }

    // Status LED bijwerken
    digitalWrite(PIN_STATUS_LED, intervalActive ? HIGH : LOW);

    // ========================================
    // CHANGE DETECTION EN RAPPORTAGE
    // ========================================

    // Repeat schakelaar wijziging
    if (repeatEnabled != prev_repeatEnabled) {
        reportStatusChange("Repeat", 
            prev_repeatEnabled ? "AAN" : "UIT", 
            repeatEnabled ? "AAN" : "UIT");
        prev_repeatEnabled = repeatEnabled;
    }

    // Interval wijziging rapporteren
    if (intervalSeconds != prev_intervalSeconds) {
        reportIntervalChange(prev_intervalSeconds, intervalSeconds);
        prev_intervalSeconds = intervalSeconds;
    }

    // Status wijziging
    if (intervalActive != prev_intervalActive) {
        if (intervalActive) {
            reportCycleStart();
        } else {
            reportCycleStop();
        }
        prev_intervalActive = intervalActive;
    }

    // Knop wijziging
    if (detectedButton != prev_detectedButton) {
        if (detectedButton > 0) {
            reportButtonChange(prev_detectedButton, detectedButton, adcValue);
        }
        prev_detectedButton = detectedButton;
    }

    // ========================================
    // KNOP VERWERKING
    // ========================================

    if (detectedButton > 0 && detectedButton != previousButton) {
        delay(DEBOUNCE_MS);

        int checkAdc = analogRead(PIN_ADC_IN);
        int checkButton = detectButtonByVoltage(checkAdc);

        if (checkButton == detectedButton) {
            activeButton = detectedButton;
            lastButtonPress = now;
            prev_intervalSeconds = intervalSeconds;

            // Stuur puls
            int muxCh = MUX_CHANNELS[activeButton];
            sendPulse(muxCh, PULS_FH2);

            // Intervalcyclus starten of stoppen (alleen voor knoppen 1-5)
            if (canRepeatWithInterval(activeButton)) {
                if (!intervalActive) {
                    intervalActive = true;
                    lastIntervalPulse = now;
                    prev_intervalActive = intervalActive;
                } else {
                    intervalActive = false;
                    digitalWrite(PIN_STATUS_LED, LOW);
                    prev_intervalActive = intervalActive;
                }
            } else {
                // Overige knoppen stoppen een actieve interval-cyclus
                if (intervalActive) {
                    intervalActive = false;
                    digitalWrite(PIN_STATUS_LED, LOW);
                    prev_intervalActive = intervalActive;
                }
            }

            previousButton = detectedButton;
        }
    }

    if (detectedButton == 0) {
        previousButton = -1;
    }

    // ========================================
    // INTERVAL PULS
    // ========================================

    if (intervalActive && repeatEnabled) {
        if (now - lastIntervalPulse >= (intervalSeconds * 1000UL)) {
            sendPulse(MUX_CHANNELS[activeButton], PULS_AUTO);
            lastIntervalPulse = now;
        }
    }

    // MUX timeout
    if (activeButton > 0 && (now - lastButtonPress >= MUX_TIMEOUT_MS)) {
        setMuxChannel(0);
    }
}

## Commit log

2026-05-11 Add README with functional and technical details
    Added detailed functional and technical descriptions for the FH-2 CQ-Machine Controller, including system operation, pin assignments, button detection, multiplexer interface, interval system, and sof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
2026-05-22 Create Mixed up buttons.md
2026-05-22 Update Mixed up buttons.md
2026-05-22 Rename Mixed up buttons.md to Mixed up buttons.txt
2026-05-24 Create Frozen control buttons.txt
